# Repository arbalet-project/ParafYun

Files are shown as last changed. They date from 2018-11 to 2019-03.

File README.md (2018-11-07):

# Paraf Project

**Paraf** is an opensource digital water curtain.

## Paraf Yún

Paraf Yún is the first version, whose conception started in October, 2018.
Yún's hardware and software resources are designed by and for University students.
Have a look to the [students' logbook](http://talk.arbalet-project.org/t/paraf-yun-en/126) ([lire en français](http://talk.arbalet-project.org/t/paraf-yun-fr/129/)).

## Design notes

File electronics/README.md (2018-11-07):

# EDA: Electronics resources

Here are specific boards made for Paraf.

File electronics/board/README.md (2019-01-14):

# BOM

Model / Package
IRF7404 / SO-8
ST485 / SO-8
ULN2803A / DW R-PDSO-G18
Crystal TXC HC-495
LMV7805 / DGK S-PDSO-G8

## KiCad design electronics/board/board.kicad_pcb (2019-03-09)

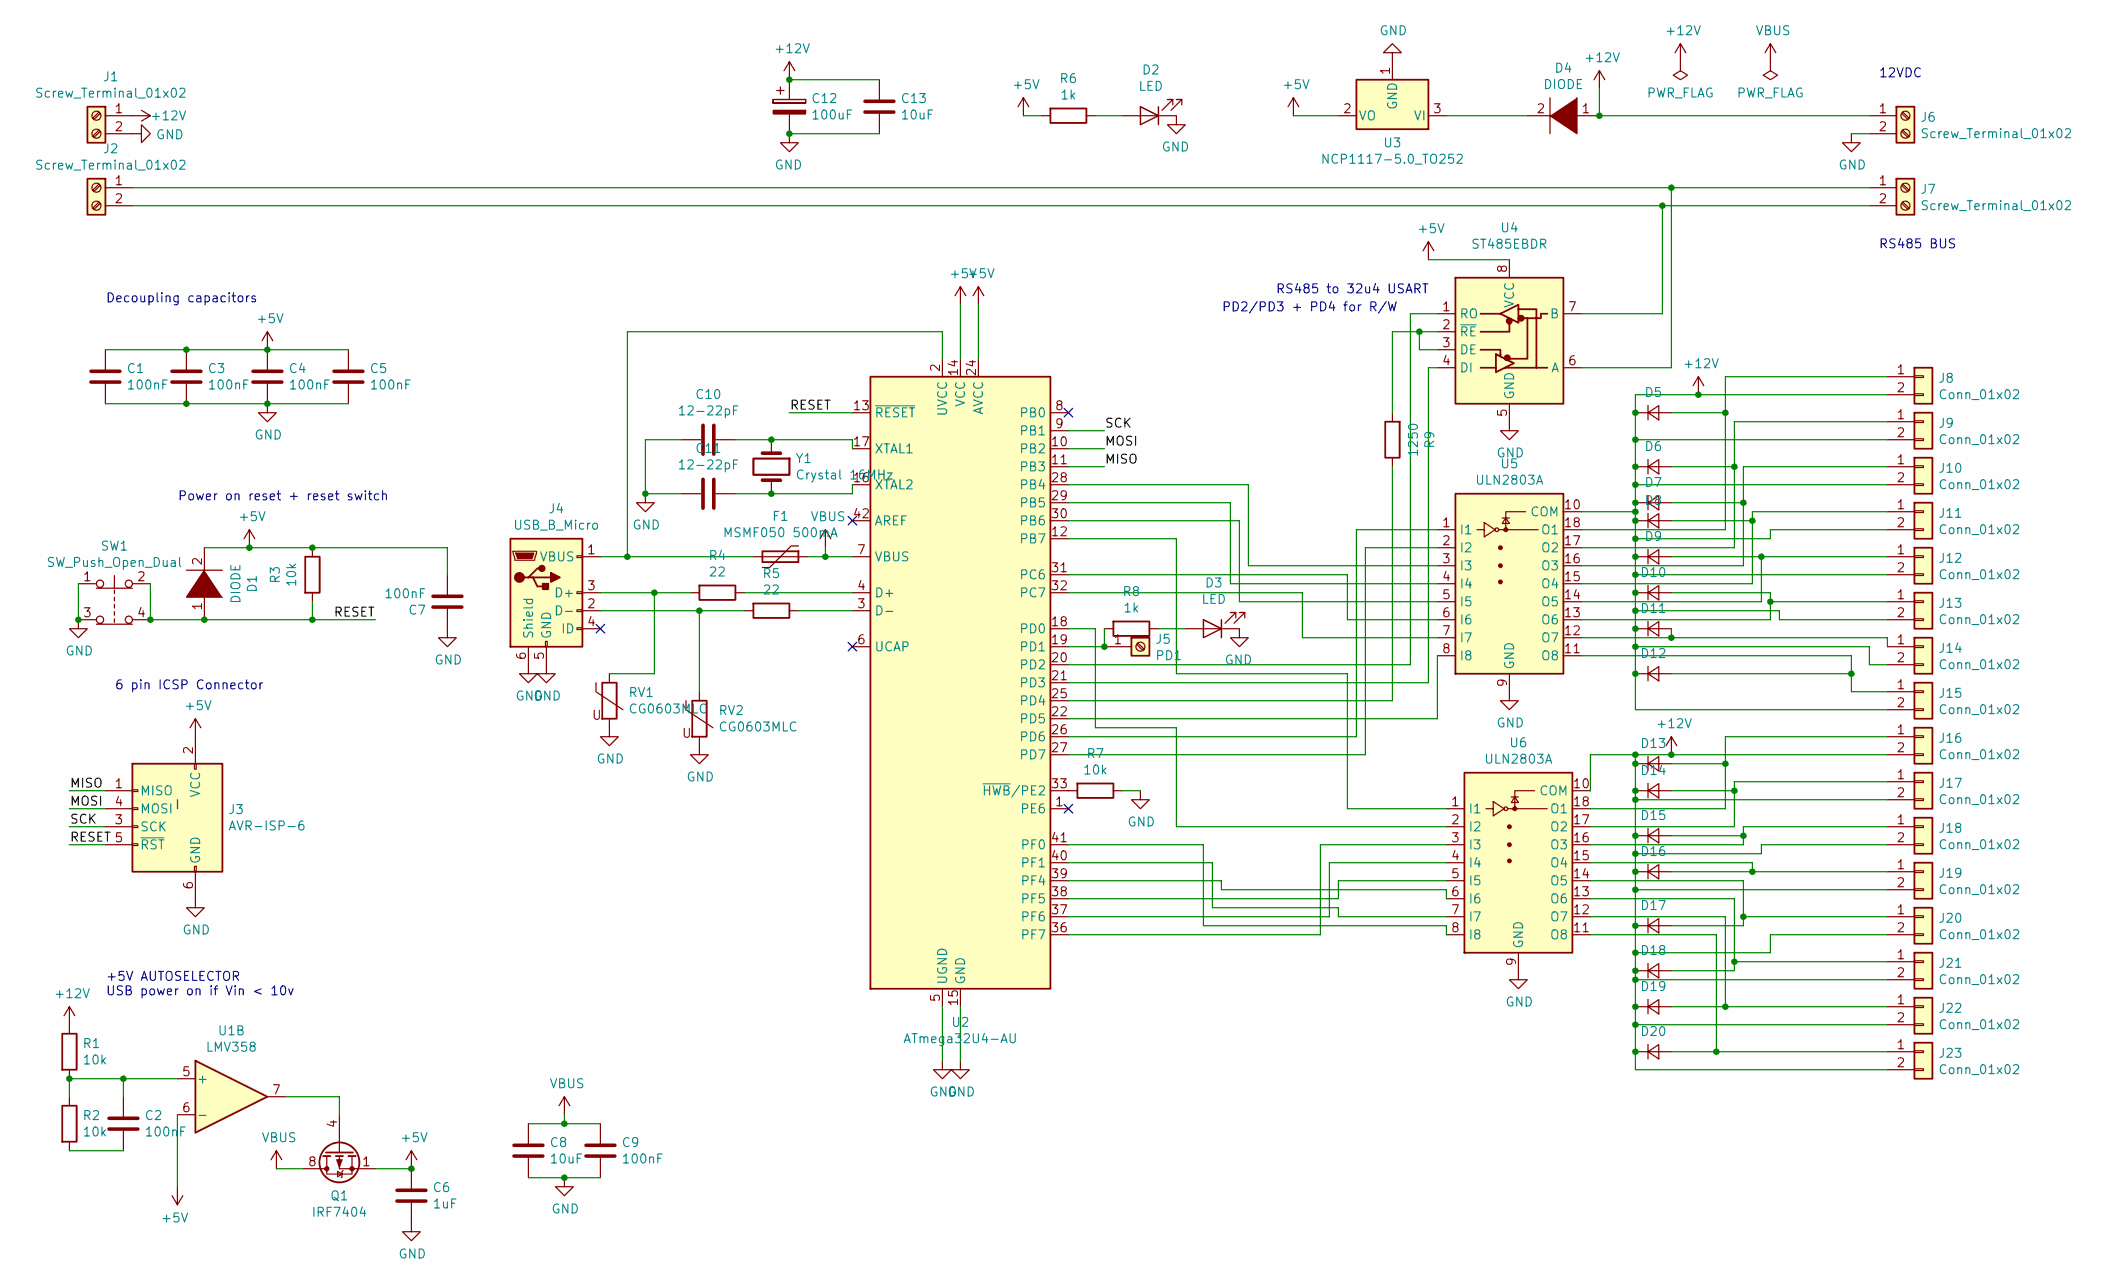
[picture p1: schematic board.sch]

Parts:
C1, C2, C3, C4, C5, C7, C9: 100nF; C_0805_2012Metric_Pad1.15x1.40mm_HandSolder
C6: 1uF; C_0805_2012Metric_Pad1.15x1.40mm_HandSolder
C8, C13: 10uF; C_0805_2012Metric_Pad1.15x1.40mm_HandSolder
C10, C11: 12-22pF; C_0805_2012Metric_Pad1.15x1.40mm_HandSolder
C12: 100uF; CP_Elec_6.3x5.2
D1: DIODE; D_0805_2012Metric_Pad1.15x1.40mm_HandSolder
D2, D3: LED; LED_0805_2012Metric
D4: DIODE; D_1206_3216Metric_Pad1.42x1.75mm_HandSolder
D5, D6, D7, D8, D9, D10, D11, D12, D13, D14, D15, D16, D17, D18, D19, D20: D; D_0805_2012Metric_Pad1.15x1.40mm_HandSolder
F1: MSMF050 500mA; Fuse_1812_4532Metric
J1, J2, J6, J7: Screw_Terminal_01x02; TerminalBlock_4Ucon_1x02_P3.50mm_Vertical
J3: AVR-ISP-6; PinHeader_2x03_P2.54mm_Vertical_SMD
J4: USB_B_Micro; USB_Micro-B_Molex_47346-0001
J5: PD1; TestPoint_Keystone_5005-5009_Compact
J8, J9, J10, J11, J12, J13, J14, J15, J16, J17, J18, J19, J20, J21, J22, J23: Conn_01x02; JST_XH_S2B-XH-A_1x02_P2.50mm_Horizontal
Q1: IRF7404; SOIC-8_3.9x4.9mm_P1.27mm
R1, R2, R3, R7: 10k; R_0805_2012Metric_Pad1.15x1.40mm_HandSolder
R4, R5: 22; R_0805_2012Metric_Pad1.15x1.40mm_HandSolder
R6, R8: 1k; R_0805_2012Metric_Pad1.15x1.40mm_HandSolder
R9: 1250; R_0805_2012Metric_Pad1.15x1.40mm_HandSolder
RV1, RV2: CG0603MLC; R_0805_2012Metric_Pad1.15x1.40mm_HandSolder
SW1: SW_Push_Open_Dual; SW_SPST_TL3342
U1: LMV358; MSOP-8-1EP_3x3mm_P0.65mm_EP2.54x2.8mm_ThermalVias
U2: ATmega32U4-AU; TQFP-44_10x10mm_P0.8mm
U3: NCP1117-5.0_TO252; TO-252-2
U4: ST485EBDR; SOIC-8_3.9x4.9mm_P1.27mm
U5, U6: ULN2803A; SOP-18_7.0x12.5mm_P1.27mm
Y1: Crystal 16MHz; Crystal_SMD_SeikoEpson_MC405-2Pin_9.6x4.1mm

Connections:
+5V: C1.1, C3.1, C4.1, C5.1, C6.1, C7.2, D1.2 (A), J3.2 (VCC), Q1.1 (S), Q1.2 (S), Q1.3 (S), R3.1, R6.2, U1.6 (-), U2.14 (VCC), U2.24 (AVCC), U2.34 (VCC), U2.44 (AVCC), U3.2 (VO), U4.8 (VCC)
+12V: C12.1, C13.1, D4.1 (K), D5.1 (K), D6.1 (K), D7.1 (K), D8.1 (K), D9.1 (K), D10.1 (K), D11.1 (K), D12.1 (K), D13.1 (K), D14.1 (K), D15.1 (K), D16.1 (K), D17.1 (K), D18.1 (K), D19.1 (K), D20.1 (K), J1.1, J6.1, J8.2, J9.2, J10.2, J11.2, J12.2, J13.2, J14.2, J15.2, J16.2, J17.2, J18.2, J19.2, J20.2, J21.2, J22.2, J23.2, R1.1, U5.10 (COM), U6.10 (COM)
/MISO: J3.1 (MISO), U2.11 (PB3)
/MOSI: J3.4 (MOSI), U2.10 (PB2)
/RESET: D1.1 (K), J3.5 (~RST), R3.2, SW1.2, SW1.4, U2.13 (~RESET)
/SCK: J3.3 (SCK), U2.9 (PB1)
GND: C1.2, C3.2, C4.2, C5.2, C6.2, C7.1, C8.2, C9.2, C10.1, C11.1, C12.2, C13.2, D2.1 (K), D3.1 (K), J1.2, J3.6 (GND), J4.5 (GND), J4.6 (Shield), J6.2, R7.1, RV1.2, RV2.2, SW1.1, SW1.3, U2.5 (UGND), U2.15 (GND), U2.23 (GND), U2.35 (GND), U2.43 (GND), U3.1 (GND), U4.5 (GND), U5.9 (GND), U6.9 (GND)
unnamed: C2.1, R1.2, R2.1, U1.5 (+)
unnamed: C2.2, R2.2
unnamed: C10.2, U2.17 (XTAL1), Y1.1
unnamed: C11.2, U2.16 (XTAL2), Y1.2
unnamed: D2.2 (A), R6.1
unnamed: D3.2 (A), R8.1
unnamed: D4.2 (A), U3.3 (VI)
unnamed: D5.2 (A), J8.1, U5.18 (O1)
unnamed: D6.2 (A), J9.1, U5.17 (O2)
unnamed: D7.2 (A), J10.1, U5.16 (O3)
unnamed: D8.2 (A), J11.1, U5.15 (O4)
unnamed: D9.2 (A), J12.1, U5.14 (O5)
unnamed: D10.2 (A), J13.1, U5.13 (O6)
unnamed: D11.2 (A), J14.1, U5.12 (O7)
unnamed: D12.2 (A), J15.1, U5.11 (O8)
unnamed: D13.2 (A), J16.1, U6.18 (O1)
unnamed: D14.2 (A), J17.1, U6.17 (O2)
unnamed: D15.2 (A), J18.1, U6.16 (O3)
unnamed: D16.2 (A), J19.1, U6.15 (O4)
unnamed: D17.2 (A), J20.1, U6.14 (O5)
unnamed: D18.2 (A), J21.1, U6.13 (O6)
unnamed: D19.2 (A), J22.1, U6.12 (O7)
unnamed: D20.2 (A), J23.1, U6.11 (O8)
unnamed: F1.2, J4.1 (VBUS), U2.2 (UVCC)
unnamed: J2.1, J7.1, U4.6 (A)
unnamed: J2.2, J7.2, U4.7 (B)
unnamed: J4.2 (D-), R5.2, RV2.1
unnamed: J4.3 (D+), R4.2, RV1.1
unnamed: J5.1, R8.2, U2.19 (PD1)
unnamed: Q1.4 (G), U1.7
unnamed: R4.1, U2.4 (D+)
unnamed: R5.1, U2.3 (D-)
unnamed: R7.2, U2.33 (~HWB~/PE2)
unnamed: R9.1, U2.25 (PD4)
unnamed: R9.2, U4.2 (~RE), U4.3 (DE)
unnamed: U2.12 (PB7), U6.1 (I1)
unnamed: U2.18 (PD0), U6.2 (I2)
unnamed: U2.20 (PD2), U4.1 (RO)
unnamed: U2.21 (PD3), U4.4 (DI)
unnamed: U2.22 (PD5), U5.8 (I8)
unnamed: U2.26 (PD6), U5.1 (I1)
unnamed: U2.27 (PD7), U5.2 (I2)
unnamed: U2.28 (PB4), U5.3 (I3)
unnamed: U2.29 (PB5), U5.4 (I4)
unnamed: U2.30 (PB6), U5.5 (I5)
unnamed: U2.31 (PC6), U5.6 (I6)
unnamed: U2.32 (PC7), U5.7 (I7)
unnamed: U2.36 (PF7), U6.3 (I3)
unnamed: U2.37 (PF6), U6.4 (I4)
unnamed: U2.38 (PF5), U6.5 (I5)
unnamed: U2.39 (PF4), U6.6 (I6)
unnamed: U2.40 (PF1), U6.7 (I7)
unnamed: U2.41 (PF0), U6.8 (I8)
VBUS: C8.1, C9.1, F1.1, Q1.5 (D), Q1.6 (D), Q1.7 (D), Q1.8 (D), U2.7 (VBUS)

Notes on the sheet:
+5V AUTOSELECTOR USB power on if Vin < 10v
12VDC
RS485 BUS
Power on reset + reset switch
Decoupling capacitors
6 pin ICSP Connector
RS485 to 32u4 USART
PD2/PD3 + PD4 for R/W

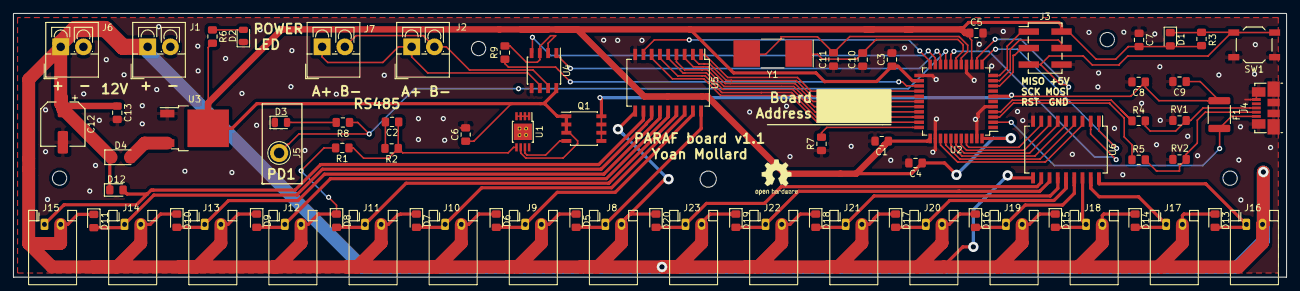
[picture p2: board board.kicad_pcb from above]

Board: 2 copper layers, 196.2 x 40.6 mm, 77 parts (0 on the bottom side), 61 nets.

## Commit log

2018-11-22 Server django de base. Il n'a rien dans le code pour le moment, on s'entraine encore sur comment fonctionne le serveur. Un repertoire static a été créé pour mettre le code front-end.
2018-11-22 Added unterminated PCB
    [board.kicad_pcb, board.sch]
2018-11-24 Bugfix style and slider
    + use regular lower case naming
2018-11-29 Suppression de polls. Début implémentation finale du back-end.
2018-11-29 Back-end fonctionnel. Il faut continuer de modifier le HTML avec les balises pour Django.
2018-12-10 Les requêtes GET et GET /sequence fonctionnent. La requête POST ne fonctionne pas pour le moment car le client connecté au serveur n'a pas de token d'authentification. Par conséquent le serveur n'acc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
2018-12-13 ajout de la fonction de sauvegarde de la séquence et des appels de fonctions dans index.html
2018-12-13 correction de bugs
2018-12-17 Board update
    [board.sch]
2018-12-17 Missing NC and PRO file update
    [board.sch]
2018-12-20 les paramètres de la séquence se mettent maintenant dans un JSON
2019-01-12 Board annotation
    [board.sch]
2019-01-14 Footprints and models
    [board.sch]
2019-01-15 485 corrections
    [board.sch]
2019-01-15 Added layout
    [board.kicad_pcb, board.sch]
2019-01-15 Footprint placement v1
    [board.kicad_pcb]
2019-01-16 5V regulator bug
    [board.kicad_pcb, board.sch]
2019-01-16 Routing update
    [board.kicad_pcb, board.sch]
2019-01-16 GND + mounting holes
    [board.kicad_pcb, board.sch]
2019-01-16 Edited Silks layers
    [board.kicad_pcb]
2019-01-16 Silk update
    [board.kicad_pcb]
2019-01-20 Transistor fix + LEDs
    [board.sch]
2019-01-20 Missing board cache
2019-01-20 Final routing and copper zones
    [board.kicad_pcb, board.sch]
2019-01-20 Switching to 0805
    [board.kicad_pcb]
2019-01-21 Diode protects only MCU
    [board.kicad_pcb, board.sch]
2019-01-21 Bugfixes R 10k and 12v track
    [board.kicad_pcb, board.sch]
2019-03-03 Board v1.1 (not routed)
    [board.kicad_pcb, board.sch]
2019-03-03 Routed 1.1
    [board.kicad_pcb, board.sch]
2019-03-07 PCB layout
    [board.kicad_pcb]
2019-03-07 cut layer + refilled zones
    [board.kicad_pcb]
2019-03-07 silk improved
    [board.kicad_pcb]
2019-03-09 Improved silk
    [board.kicad_pcb]
